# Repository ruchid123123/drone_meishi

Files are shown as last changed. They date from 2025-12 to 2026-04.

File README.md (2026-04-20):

# ESP32 Mini Drone FC

Please see the blog post for full details.
https://fumimaker.net/drone_business_card_rev32

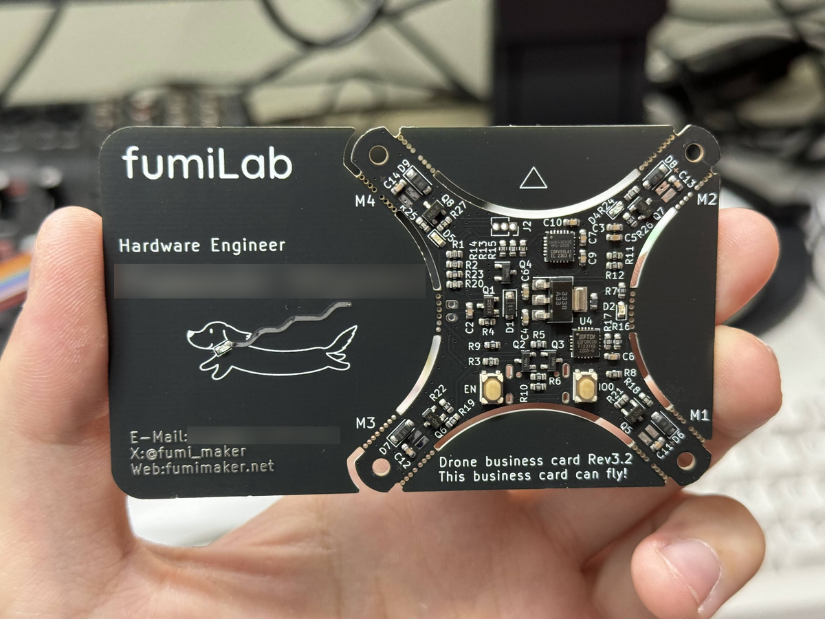
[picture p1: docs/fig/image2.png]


## Overview

Firmware for an ESP32-based micro drone FC with IMU fusion, PID control, and a Web UI controller.

YouTube (https://www.youtube.com/watch?v=yCas-xbfeBE)

---

# ESP32 迷你无人机飞控

详情请参阅博客文章：
https://fumimaker.net/drone_business_card_rev32

## 概述

基于 ESP32 的微型无人机飞控固件，具备 IMU 数据融合、PID 控制和 Web UI 控制器功能。

## 运行时参数

- 控制循环：500 Hz（IMU 读取、姿态估计、PID、电机输出）
- 电机 PWM：20 kHz
- WebSocket 控制输入：50 Hz（Web UI）
- 遥测数据：默认 20 Hz
- Web 服务器/WebSocket：通过 ESPAsyncWebServer + AsyncTCP 事件驱动

## 依赖库

- ESPAsyncWebServer
- AsyncTCP

## 烧录步骤

1. 安装 Arduino IDE + ESP32 核心库
2. 安装上述依赖库
3. 选择 **ESP32 Devkit** 并上传

## 使用方法

1. 上电：ESP32 启动 Wi-Fi 热点
   - SSID: `ESP32-DRONE`
   - 密码: `12345678`
2. 连接后打开 `http://192.168.4.1/`
3. 在 **SETTINGS** 中进行校准：先校准陀螺仪(GYRO)，再校准加速度计(ACC)
4. 如需调整，修改 PID 参数，然后点击 **SAVE** 保存
5. 切换到 **CONTROL** 页面，启用 **ARM**（约 800 秒后解锁），然后飞行
6. **DISARM** 立即停止；倾斜角度 > ~80° 自动解锁

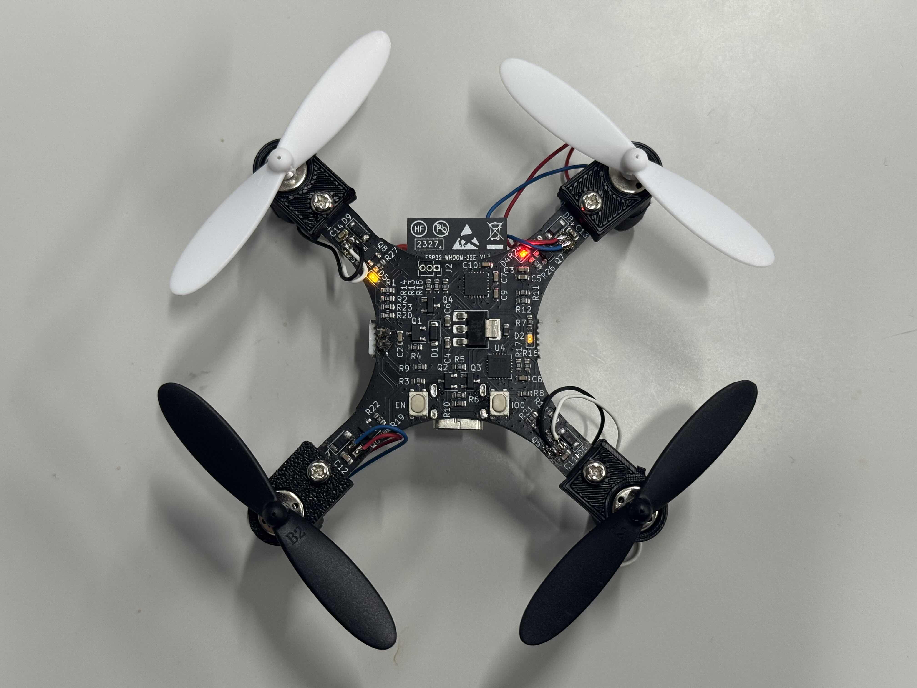
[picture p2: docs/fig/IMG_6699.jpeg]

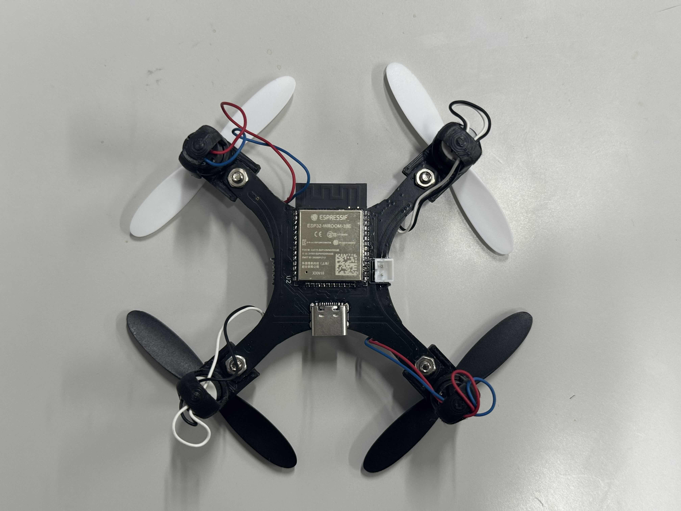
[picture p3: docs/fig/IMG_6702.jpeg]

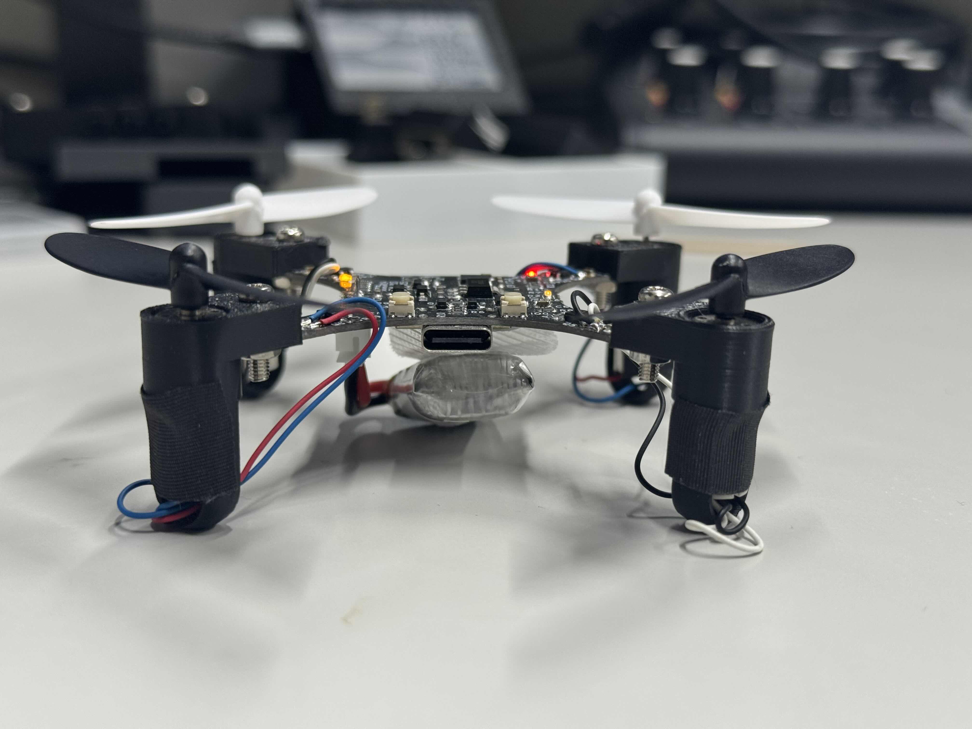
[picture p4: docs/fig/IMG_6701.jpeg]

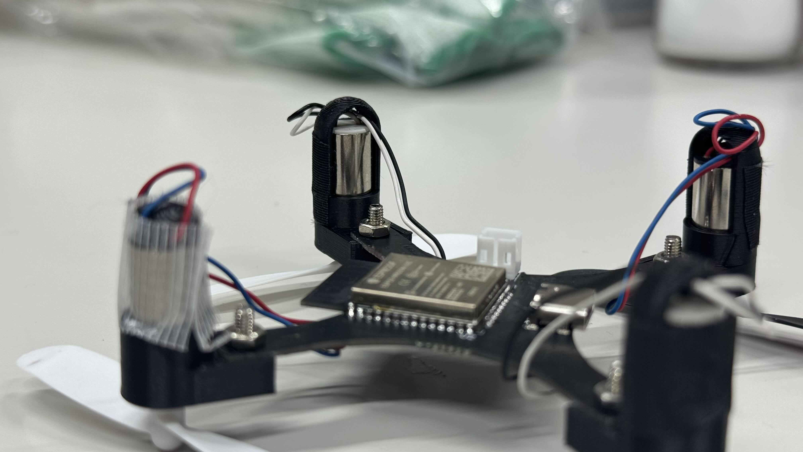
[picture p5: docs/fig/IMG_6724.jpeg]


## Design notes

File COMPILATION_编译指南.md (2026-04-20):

# ESP32 迷你无人机飞控 - 编译指南 (2026年版)

本指南详细说明了如何在受限网络环境下，利用国内加速镜像和 Docker 成功编译本项目。

---

## 1. 快速开始 (推荐方案：Docker 挂载模式)

由于 ESP32 工具链体积庞大（约 300MB+），在 Docker 内部直接下载极易失败。推荐在宿主机下载环境后，通过 Docker 挂载运行。

### 准备环境 (宿主机)
1. **安装工具**：确保 `arduino-cli` 已安装（本项目路径为 `/home/j/bin/arduino-cli`）。
2. **配置国内加速镜像** (乐鑫官方极狐镜像)：
   ```bash
   arduino-cli config init --overwrite
   arduino-cli config add board_manager.additional_urls https://jihulab.com/esp-mirror/espressif/arduino-esp32/-/raw/gh-pages/package_esp32_index_cn.json
   arduino-cli core update-index
   ```
3. **安装核心库** (必须带 `-cn` 后缀以触发国内加速)：
   ```bash
   arduino-cli core install esp32:esp32@3.0.7-cn
   ```
4. **安装依赖库**：
   ```bash
   arduino-cli lib install "ESPAsyncWebServer" "AsyncTCP"
   ```

### 使用 Docker 编译
运行项目根目录下的脚本：
```bash
chmod +x docker_compile.sh
./docker_compile.sh
```
该脚本会将宿主机的 `~/.arduino15`（环境）和 `~/Arduino/libraries`（库）挂载到容器中，实现环境隔离与高速编译的平衡。

---

## 2. 关键补丁与修复 (已在本项目中应用)

在编译过程中，我们解决了以下两个核心冲突，后续开发请务必注意：

### 2.1 修复代码重定义错误
在 `drone_meishi.ino` 中，`kEnableSerialAttDebug` 曾被定义了两次，导致编译失败。已删除冗余定义。

### 2.2 修复 ESPAsyncWebServer 兼容性
由于 ESP32 Arduino Core 3.0.x 升级了 `mbedtls` 库，旧版 `ESPAsyncWebServer` 中的加密函数后缀不匹配。需对库文件进行如下替换：
- `mbedtls_md5_starts_ret` -> `mbedtls_md5_starts`
- `mbedtls_md5_update_ret` -> `mbedtls_md5_update`
- `mbedtls_md5_finish_ret` -> `mbedtls_md5_finish`
*注：本项目宿主机环境已完成此修复。*

---

## 3. 故障排除

### 网络超时
- **Docker 拉取镜像慢**：已配置 `/etc/docker/daemon.json` 使用国内镜像（如 `docker.xuanyuan.me`）。
- **Arduino 核心库下载失败**：请检查是否使用了 `package_esp32_index_cn.json` 并选择了 `-cn` 版本。

### 编译命令参考
- **完整编译指令**：
  ```bash
  arduino-cli compile --fqbn esp32:esp32:esp32 drone_meishi/drone_meishi.ino
  ```

---

## 4. 文件说明
- `Dockerfile.build`：用于构建基础编译镜像。
- `docker_compile.sh`：一键调用 Docker 进行编译的入口。
- `arduino-cli-bin`：为 Docker 构建准备的本地工具二进制文件。

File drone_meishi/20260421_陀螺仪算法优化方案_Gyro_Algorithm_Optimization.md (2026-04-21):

# 陀螺仪算法优化方案 (2026-04-21)

针对本项目（Drone Meishi）使用的 MPU6050 硬件及 Mahony/Madgwick 融合算法，提出以下优化路径，旨在提升飞行稳定性、减少姿态漂移并增强抗震动能力。

## 1. 硬件层优化 (MPU6050 配置)
*   **启用内置数字低通滤波器 (DLPF)**：目前驱动层可以增加对 `CONFIG (0x1A)` 寄存器的配置。建议将 DLPF 设置为 42Hz 或 20Hz，以在源头上滤除电机高频机械振动。
*   **采样率同步**：确保 MPU6050 的内部采样率（Sample Rate）与飞控主循环（500Hz）保持倍数同步，减少混叠噪声。

## 2. 核心算法改进 (Mahony/Madgwick)
*   **动态增益控制 (Adaptive Gains)**：
    *   **运动感知**：在检测到剧烈加速或旋转时，动态降低加速度计的反馈权重（Kp/Beta），防止非重力加速度干扰姿态。
    *   **静止校准**：在检测到长期静止时，提高权重以快速修正陀螺仪的累积漂移。
*   **加速度计阈值剔除 (G-vector Clipping)**：在 Mahony 算法中加入逻辑：当 `|Acc_total - 1G| > Threshold` 时，暂时停止加速度计的反馈修正。

## 3. 信号处理优化
*   **软件陷波滤波器 (Notch Filter)**：针对电机转速产生的特定频率干扰（通常在 150Hz-300Hz 之间），在 IMU 原始数据进入算法前增加陷波滤波，这比通用的低通滤波更精准且延迟更低。
*   **零偏动态温度补偿**：利用 MPU6050 内置温度计，建立简单的线性模型 `Bias = k * Temp + b`，解决无人机工作一段时间发热后产生的侧偏现象。

## 4. 系统执行优化 (ESP32 特性)
*   **多核并行处理**：将 `IMU Read + AHRS Update` 任务锁定在 ESP32 的 Core 0 运行，而将 `Web UI + WiFi` 锁定在 Core 1。避免网络协议栈阻塞导致的姿态计算抖动。
*   **使用硬件浮点优化**：确保算法实现中大量使用 `float` 而非 `double`，并调用 ESP32 的 `rsqrtf` 等 FPU 优化函数进行四元数归一化。

## 5. 预期效果
*   **抗干扰性**：在电机高速转动下，姿态抖动幅度预计降低 30% 以上。
*   **响应速度**：通过减少软件滤波延迟，提升飞控对外部扰动的纠正速度。
*   **长时稳定性**：航向漂移和水平漂移在 5 分钟飞行任务中将更加线性可控。

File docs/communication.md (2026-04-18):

# Communication Architecture

---

## 1. システム全体図

操縦者(スマホ) ↔ ドローン本体(ESP32) ↔ センサ/アクチュエータ、およびオプションのPC接続を含む全体像。

```mermaid
flowchart LR
    subgraph Operator["操縦側"]
        Phone["スマホ / PCブラウザ<br/>Web UI"]
        ProcPC["PC<br/>Processing Viewer<br/>(姿勢可視化)"]
    end

    subgraph Drone["ドローン本体"]
        ESP["ESP32 DevKit<br/>Flight Controller"]
        IMU["MPU6050<br/>6軸IMU"]
        ESC["4× Motor / ESC<br/>(M0–M3)"]
        NVS[("NVS Flash<br/>PID/Cal保存")]
    end

    Phone <-->|"Wi-Fi 2.4GHz<br/>SoftAP: ESP32-DRONE<br/>HTTP/WebSocket :80"| ESP
    ESP <-->|"I2C 400kHz<br/>SDA=21 / SCL=22<br/>addr 0x68"| IMU
    ESP -->|"PWM 20kHz / 11bit<br/>GPIO 15,13,12,14"| ESC
    ESP <-->|"内蔵SPI Flash"| NVS
    ESP -.->|"USB UART 115200bps<br/>(オプション)"| ProcPC
```

---

## 2. 機体プロペラ配置（Xクアッド）

WebSocket経由の `roll/pitch/yaw/throttle` をモータミキシングで4基に配分。

```mermaid
flowchart TB
    subgraph Frame[" "]
        direction TB
        FRONT(("▲ Front"))
        M0["M0 (FL)<br/>GPIO15<br/>CCW"]
        M1["M1 (FR)<br/>GPIO13<br/>CW"]
        M3["M3 (RL)<br/>GPIO14<br/>CW"]
        M2["M2 (RR)<br/>GPIO12<br/>CCW"]
        FRONT -.- M0
        FRONT -.- M1
    end

    Mix["Motor Mix (X)<br/>M0 = T + R + P − Y<br/>M1 = T − R + P + Y<br/>M2 = T − R − P − Y<br/>M3 = T + R − P + Y"]
    Mix --> M0
    Mix --> M1
    Mix --> M2
    Mix --> M3
```

---

## 3. 制御ループ（500 Hz）

メインループの内部データフロー。IMU読み出しからモータ出力までを2ms周期で回す。

```mermaid
flowchart LR
    A["① IMU読み出し<br/>I2C 14byte"] --> B["② AHRS推定<br/>Mahony / Madgwick / Comp"]
    B --> C["③ 角度PID<br/>(roll/pitch/yaw)"]
    C --> D["④ レートPID"]
    D --> E["⑤ モータミキシング<br/>X-quad"]
    E --> F["⑥ PWM出力<br/>LEDC 20kHz/11bit"]

    G["WebSocket入力<br/>throttle/roll/pitch/yaw"] --> C
    H["フェイルセーフ判定<br/>WS切断/タイムアウト/傾き>80°"] -.-> E
```

---

## 4. WebSocket メッセージ仕様

ブラウザ ↔ ESP32 (`ws://192.168.4.1/ws`) はテキストCSV/JSON。

### Client → Drone

| Type | Format | 用途 | レート |
|---|---|---|---|
| `C` | `C,throttle,roll,pitch,yaw,arm` | 操縦入力 | 50 Hz |
| `PID` | `PID,ANGLE\|RATE\|YAW,kp,ki,kd` | PIDゲイン更新 | 任意 |
| `CFG` | `CFG,KEY,VALUE` | 設定変更 | 任意 |
| `CAL` | `CAL,LEVEL\|GYRO` | キャリブレーション要求 | 任意 |
| `MTEST` | `MTEST,idx,thr,dur_ms` / `MTEST,STOP` | モータテスト | 任意 |
| `GET` | `GET` | 設定同期要求 | 接続時 |
| `SAVE` | `SAVE` | NVSへ保存 | 任意 |
| `K` | `K` | 強制Disarm | 任意 |

### Drone → Client (JSON)

| Type | 主なフィールド | 用途 | レート |
|---|---|---|---|
| `tel` | `t, armed, roll, pitch, yaw, m0..m3, vbatt, loop_hz, fs, cmd_age` | テレメトリ | 20 Hz |
| `cfg` | PID/制限/オフセット一式 | 接続時の設定通知 | 接続時 |
| `ack` | `op, tag, ok, msg` | コマンド応答 | 都度 |

### 操縦シーケンス例

```mermaid
sequenceDiagram
    participant B as 📱 Browser
    participant E as ESP32 (FC)
    participant I as MPU6050
    participant M as Motors

    B->>E: HTTP GET /  (UI HTML)
    B->>E: WS connect /ws
    E-->>B: cfg (現在のPID/設定)
    loop 50Hz
        B->>E: C,throttle,roll,pitch,yaw,arm
    end
    loop 500Hz (内部)
        E->>I: I2C read 14B
        I-->>E: ax,ay,az,gx,gy,gz
        E->>M: PWM (M0..M3)
    end
    loop 20Hz
        E-->>B: tel JSON
    end
    Note over B,E: WS切断 → 即Disarm<br/>cmd_age > 300ms → Disarm
```

---

## 5. ピン/ポート割当

| 機能 | 信号 | GPIO / ポート | 備考 |
|---|---|---|---|
| I2C IMU | SDA | GPIO 21 | 400 kHz |
| I2C IMU | SCL | GPIO 22 | addr 0x68 |
| Motor M0 (FL) | PWM | GPIO 15 | LEDC ch0 |
| Motor M1 (FR) | PWM | GPIO 13 | LEDC ch1 |
| Motor M2 (RR) | PWM | GPIO 12 | LEDC ch2 |
| Motor M3 (RL) | PWM | GPIO 14 | LEDC ch3 |
| Web Server | TCP | :80 (HTTP / WS) | ESPAsyncWebServer |
| Wi-Fi | SoftAP | 2.4GHz | SSID `ESP32-DRONE` / IP `192.168.4.1` |
| Debug | UART0 | USB | 115200 bps |

---

## 6. フェイルセーフ

| トリガ | 動作 | 備考 |
|---|---|---|
| WebSocket切断 | 即Disarm | `FS_WS_DISCONNECT` |
| 操縦コマンド未受信 > 300ms | Disarm | `cmd_to` で変更可 |
| 機体傾き > 80° | Auto Disarm | `tilt_dis` で変更可 |
| IMU異常 | Disarm | 姿勢推定値が不正な場合 |
| Armラッチ後の再Arm抑止 | キル状態保持 | 明示的にDisarm要求が必要 |

---

## 7. 通信
操縦は **Wi-Fi WebSocket**
ライブラリ依存は `ESPAsyncWebServer` / `AsyncTCP`

以下は使用していません．
- SBUS（プロポ受信機）
- ESP-NOW
- Bluetooth
- MAVLink / CRSF / S.Port 等のテレメトリ規格

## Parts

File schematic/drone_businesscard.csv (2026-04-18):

Reference | Qty | Value | DNP | Exclude from BOM | Exclude from Board | Footprint | Datasheet
C1 | 1 | DNP |  |  |  | Capacitor_SMD:C_0603_1608Metric | ~
C2,C5,C7,C8,C9,C10,C11,C12,C13,C14 | 10 | 0.1u |  |  |  | Capacitor_SMD:C_0603_1608Metric | ~
C3,C4,C6 | 3 | 10u |  |  |  | Capacitor_SMD:C_0603_1608Metric | ~
D1 | 1 | MBR0520 |  |  |  | Diode_SMD:D_SOD-123 | http://www.mccsemi.com/up_pdf/MBR0520~MBR0580(SOD123).pdf
D2 | 1 | blue |  |  |  | LED_SMD:LED_0603_1608Metric | ~
D3,D4 | 2 | red |  |  |  | LED_SMD:LED_0603_1608Metric | ~
D5 | 1 | green |  |  |  | LED_SMD:LED_0603_1608Metric | ~
D6,D7,D8,D9 | 4 | 1N4148W |  |  |  | Diode_SMD:D_SOD-123 | https://www.vishay.com/docs/85748/1n4148w.pdf
FB1 | 1 | FerriteBead |  |  |  | Inductor_SMD:L_0603_1608Metric | ~
J1 | 1 | LIPO |  |  |  | Connector_JST:JST_PH_B2B-PH-K_1x02_P2.00mm_Vertical | ~
J2 | 1 | Conn_01x03_Pin |  |  |  | Connector_PinSocket_1.27mm:PinSocket_1x03_P1.27mm_Vertical | ~
J3 | 1 | M1 |  |  |  | Akizuki:1x02_smd_pad | ~
J4 | 1 | M3 |  |  |  | Akizuki:1x02_smd_pad | ~
J5 | 1 | M2 |  |  |  | Akizuki:1x02_smd_pad | ~
J6 | 1 | M4 |  |  |  | Akizuki:1x02_smd_pad | ~
P1 | 1 | USB_C_Plug_USB2.0 |  |  |  | Connector_USB:USB_C_Receptacle_HCTL_HC-TYPE-C-16P-01A | https://www.usb.org/sites/default/files/documents/usb_type-c.zip
Q1 | 1 | AO3401A |  |  |  | Package_TO_SOT_SMD:SOT-23 | http://www.aosmd.com/pdfs/datasheet/AO3401A.pdf
Q2,Q3,Q4 | 3 | MMBT3904 |  |  |  | Package_TO_SOT_SMD:SOT-23 | https://www.onsemi.com/pdf/datasheet/pzt3904-d.pdf
Q5,Q6,Q7,Q8 | 4 | AO3400A |  |  |  | Package_TO_SOT_SMD:SOT-23 | http://www.aosmd.com/pdfs/datasheet/AO3400A.pdf
R1,R2 | 2 | 2.2k |  |  |  | Resistor_SMD:R_0603_1608Metric | ~
R3,R4,R5,R6,R7,R8,R9,R11,R12,R14,R15,R21,R22,R26,R27 | 15 | 10k |  |  |  | Resistor_SMD:R_0603_1608Metric | ~
R10 | 1 | 5.1k |  |  |  | Resistor_SMD:R_0603_1608Metric | ~
R13,R16,R17,R18,R19,R20,R23,R24,R25 | 9 | 1k |  |  |  | Resistor_SMD:R_0603_1608Metric | ~
SW1,SW2 | 2 | SW_MEC_5E |  |  |  | module:SKRPACE010 | http://www.apem.com/int/index.php?controller=attachment&id_attachment=1371
U1 | 1 | LT1117-3.3 |  |  |  | Package_TO_SOT_SMD:SOT-223-3_TabPin2 | https://www.analog.com/media/en/technical-documentation/data-sheets/1117fd.pdf
U2 | 1 | ESP32-WROOM-32D |  |  |  | RF_Module:ESP32-WROOM-32D | https://www.espressif.com/sites/default/files/documentation/esp32-wroom-32d_esp32-wroom-32u_datasheet_en.pdf
U3 | 1 | MPU-6050 |  |  |  | Sensor_Motion:InvenSense_QFN-24_4x4mm_P0.5mm | https://invensense.tdk.com/wp-content/uploads/2015/02/MPU-6000-Datasheet1.pdf
U4 | 1 | FT231XQ |  |  |  | Package_DFN_QFN:QFN-20-1EP_4x4mm_P0.5mm_EP2.5x2.5mm | https://www.ftdichip.com/Support/Documents/DataSheets/ICs/DS_FT231X.pdf

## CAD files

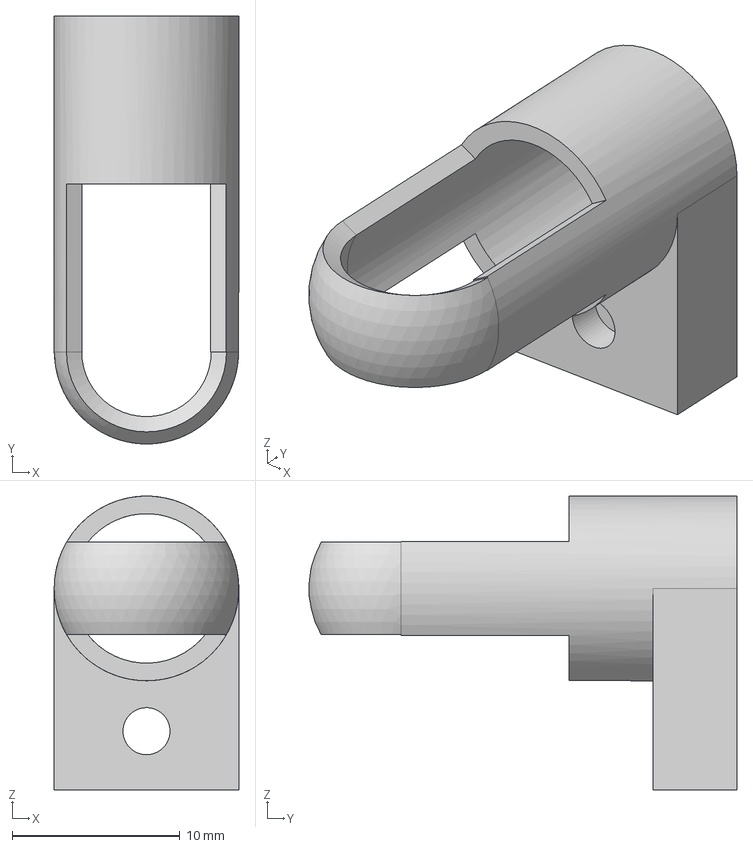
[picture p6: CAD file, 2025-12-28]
3dmodel/drone_meishi3.step
11.0 x 25.5 x 17.5 mm

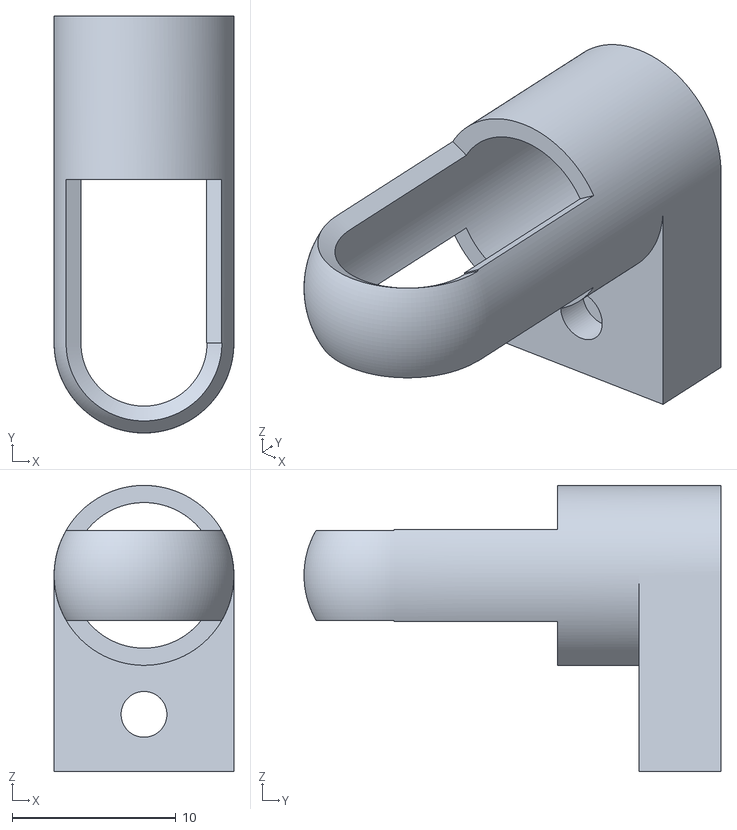
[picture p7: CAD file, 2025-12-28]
3dmodel/drone_meishi.stl
11.0 x 25.5 x 17.5

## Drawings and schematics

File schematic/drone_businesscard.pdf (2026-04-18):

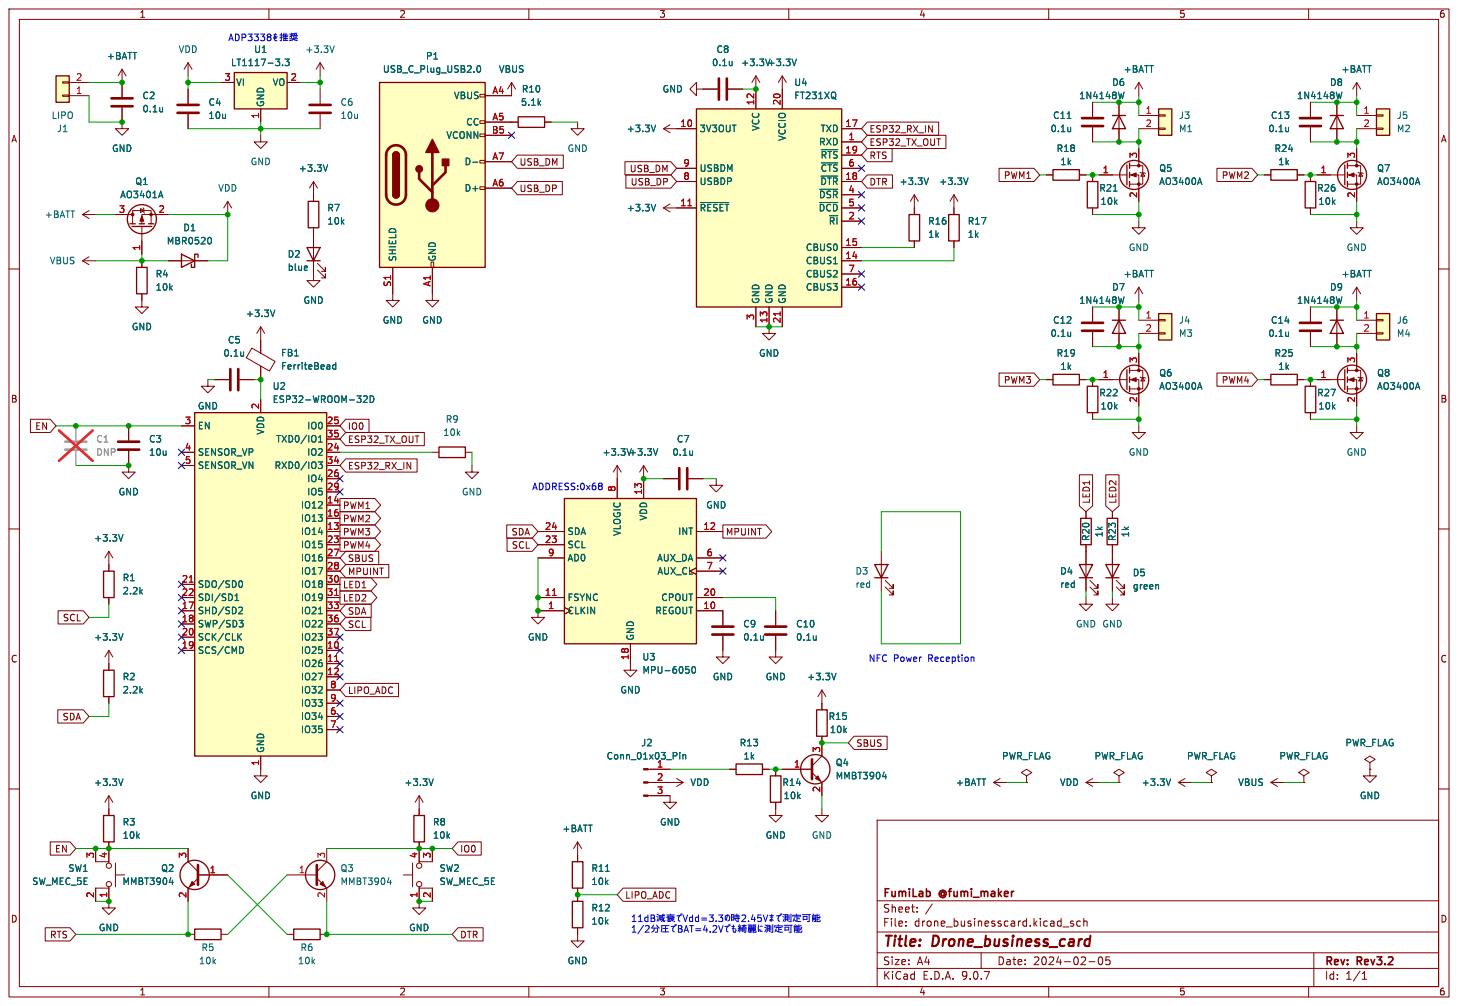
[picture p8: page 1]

3 2 Q5 AO3400A SHIELD S1 GND A1 VBUS A4 CC A5 VCONN B5 D- A7 D+ A6 P1 USB_C_Plug_USB2.0 +3.3V C6

3 GND 13 VCCIO 20 GND 21 TXD 17 RXD 1 ~{RTS}19 ~{CTS}6 ~{DTR}18 ~{DSR}4 ~{DCD}5 ~{RI}2 CBUS0 15 CBUS1 14 CBUS2 7 CBUS3 16 +3.3V +3.3V GND

3 GND 13 VCCIO 20 GND 21 TXD 17 RXD 1 ~{RTS}19 ~{CTS}6 ~{DTR}18 ~{DSR}4 ~{DCD}5 ~{RI}2 CBUS0 15 CBUS1 14 CBUS2 7 CBUS3 16 U4 FT231XQ

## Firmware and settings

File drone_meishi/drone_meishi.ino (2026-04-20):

#include <Arduino.h>
#include <AsyncTCP.h>
#include <ESPAsyncWebServer.h>
#include <Preferences.h>
#include <WiFi.h>
#include <Wire.h>
#include <math.h>
#include <string.h>
#include <esp32-hal-ledc.h>
#include "drone_types.h"

// ============================================================
// Pin Configuration / 引脚配置
// ============================================================

// WiFi AP settings / WiFi 热点设置
static const char *kApSsid = "ESP32-DRONE";
static const char *kApPass = "12345678";

// I2C pins / I2C 引脚
static const int kI2cSda = 21;
static const int kI2cScl = 22;
static const uint8_t kMpuAddr = 0x68;

// IMU axis mapping (sensor -> body frame)
// Configure these to match your board orientation.
// IMU 轴向映射（传感器 -> 机体坐标系），根据板子方向配置。
static const bool kImuSwapXY = true;
static const bool kImuFlipX = true;   // Right roll -> positive
static const bool kImuFlipY = true;   // Pitch up -> positive
static const bool kImuFlipZ = false;

// Motors (X configuration) / 电机（X 型布局）
// Front is between M0/M1. Order: FL, FR, RR, RL
// 前方在 M0/M1 之间。顺序：前左、前右、后右、后左
static const int kMotor0Pin = 15;  // Front Left
static const int kMotor1Pin = 13;  // Front Right
static const int kMotor2Pin = 12;  // Rear Right
static const int kMotor3Pin = 14;  // Rear Left

static const float kMotorTestMaxThrottle = 0.20f;
static const uint32_t kMotorTestMinMs = 100;
static const uint32_t kMotorTestMaxMs = 2000;

// LEDs (LED1: right, LED2: left) / LED（LED1：右，LED2：左）
static const int led1 = 18;
static const int led2 = 19;

// PWM settings / PWM 设置
static const uint32_t kPwmFreqHz = 20000;
static const uint8_t kPwmResolutionBits = 11;
static const uint32_t kPwmMaxDuty = (1U << kPwmResolutionBits) - 1U;

static const uint32_t kLedPwmFreqHz = 1000;
static const uint8_t kLedPwmResolutionBits = 8;
static const uint32_t kLedPwmMaxDuty = (1U << kLedPwmResolutionBits) - 1U;


// Control loop timing / 控制循环时序
static const uint32_t kLoopPeriodUs = 2000;  // 500Hz
static const float kDtMaxSec = 0.02f;

// RC and arming parameters / 遥控和解锁参数
static const uint32_t kDefaultCmdTimeoutMs = 300;
static const uint32_t kMinCmdTimeoutMs = 100;
static const uint32_t kMaxCmdTimeoutMs = 2000;
static const float kArmThrottleMax = 0.05f;
static const float kStickCenterMax = 0.15f;
static const uint32_t kArmHoldMs = 800;

// Torque scaling / 扭矩缩放
// Helps avoid lift at very low throttle.
// 防止在低油门时产生升力。
static const float kDefaultTorqueScaleSlope = 2.0f;  // throttle * slope -> torque scale (0..1)
static const float kDefaultTorqueScaleMin = 0.20f;   // floor to keep some authority at 0 throttle
static const float kMinTorqueScaleSlope = 0.0f;
static const float kMaxTorqueScaleSlope = 4.0f;
static const float kMinTorqueScaleMin = 0.0f;
static const float kMaxTorqueScaleMin = 1.0f;

// Flight limits / 飞行限制
static const float kDefaultMaxAngleDeg = 30.0f;
static const float kMinMaxAngleDeg = 5.0f;
static const float kMaxMaxAngleDeg = 80.0f;
static const float kDefaultMaxYawRateDps = 180.0f;
static const float kMinMaxYawRateDps = 30.0f;
static const float kMaxMaxYawRateDps = 360.0f;
static const float kDefaultTiltDisarmDeg = 80.0f;
static const float kMinTiltDisarmDeg = 20.0f;
static const float kMaxTiltDisarmDeg = 85.0f;

// Telemetry / 遥测
static const uint32_t kDefaultTelemPeriodMs = 50;  // 20Hz
static const uint32_t kMinTelemPeriodMs = 20;
static const uint32_t kMaxTelemPeriodMs = 500;

// IMU filter settings / IMU 滤波器设置
static const float kMadgwickBeta = 0.08f;
static const float kMadgwickBetaMin = 0.02f;
static const float kMadgwickBetaMax = 0.14f;

// Betaflight-style Mahony (DCM) gains / Betaflight 风格 Mahony 增益
// - Kp: proportional correction strength / 比例校正强度
// - Ki: integral correction strength / 积分校正强度
static const float kMahonyKp = 2.2f;
static const float kMahonyKi = 0.0f;
static const float kMahonyIntegralLimitRads = 0.35f;  // clamp for bias estimate (rad/s)
static const float kMahonySpinLimitDps = 180.0f;      // disable integral update above this rate

static const float kAccTrustHi = 0.08f;  // |norm-1| <= this -> full trust
static const float kAccTrustLo = 0.35f;  // |norm-1| >= this -> no trust

enum FilterMode : uint8_t {
  FILTER_MADGWICK = 0,
  FILTER_MAHONY = 1,
  FILTER_COMP = 2,
};

// Default AHRS mode. For Angle flight, Mahony is usually a good starting point.
static const FilterMode kFilterMode = FILTER_MAHONY;

static const float kCompAlpha = 0.98f;  // complementary blend (gyro vs acc)

static const float kRelevelAccTolG = 0.10f;
static const float kRelevelGyroDps = 1.5f;
static const uint32_t kRelevelHoldMs = 400;

// Battery telemetry / 电池遥测

static const int kVbattAdcPin = -1;         // e.g. 34
static const float kVbattDividerRatio = 2.0f;  // voltage divider ratio (VBAT = Vadc * ratio)

// Debug output / 调试输出
static const bool kEnableSerialAttDebug = false;  // High-rate attitude output / 高速姿态输出

// ============================================================
// Utilities
// ============================================================

static inline float clampf(float v, float vmin, float vmax) {
  if (v < vmin) {
    return vmin;
  }
  if (v > vmax) {
    return vmax;
  }
  return v;
}

static inline uint32_t clampu32(uint32_t v, uint32_t vmin, uint32_t vmax) {
  if (v < vmin) {
    return vmin;
  }
  if (v > vmax) {
    return vmax;
  }
  return v;
}

static inline bool isFinitef(float v) {
  return isfinite(v) != 0;
}

// ============================================================
// LED status
// ============================================================
#include "drone_led.h"

// ============================================================
// Web UI
// ============================================================
#include "drone_web_ui.h"

// ============================================================
// RC command
// ============================================================

static RcCommand g_rc = {0.0f, 0.0f, 0.0f, 0.0f, false, 0};
static portMUX_TYPE g_rcMux = portMUX_INITIALIZER_UNLOCKED;

static RcCommand getRcCommand() {
  RcCommand out;
  portENTER_CRITICAL(&g_rcMux);
  out = g_rc;
  portEXIT_CRITICAL(&g_rcMux);
  return out;
}

static void setRcCommand(float throttle, float roll, float pitch, float yaw, bool arm_request) {
  portENTER_CRITICAL(&g_rcMux);
  g_rc.throttle = clampf(throttle, 0.0f, 1.0f);
  g_rc.roll = clampf(roll, -1.0f, 1.0f);
  g_rc.pitch = clampf(pitch, -1.0f, 1.0f);
  g_rc.yaw = clampf(yaw, -1.0f, 1.0f);
  g_rc.arm_request = arm_request;
  g_rc.last_ms = millis();
  portEXIT_CRITICAL(&g_rcMux);
}

// ============================================================
// PID
// ============================================================
#include "drone_pid.h"

// ============================================================
// Madgwick IMU-only
// ============================================================
#include "drone_imu.h"

// ============================================================
// PID tunings + NVS
// ============================================================

static RuntimeConfig g_config = {
  kDefaultMaxAngleDeg,
  kDefaultMaxYawRateDps,
  kDefaultTiltDisarmDeg,
  kDefaultCmdTimeoutMs,
  kDefaultTelemPeriodMs,
  kDefaultTorqueScaleMin,
  kDefaultTorqueScaleSlope,
};

static Tunings g_tunings = {
  {2.0f, 0.001f, 0.0f},     // angle
  {0.025f, 0.0f, 0.0002f},  // rate
  {0.030f, 0.0f, 0.0f},     // yaw
};

static float g_level_roll_offset_deg = 0.0f;
static float g_level_pitch_offset_deg = 0.0f;
static float g_level_yaw_offset_deg = 0.0f;

static volatile bool g_tunings_dirty = false;
static portMUX_TYPE g_cfgMux = portMUX_INITIALIZER_UNLOCKED;

// Active AHRS mode (switchable). Protected by g_cfgMux.
static FilterMode g_filter_mode = kFilterMode;

static Preferences g_prefs;

static void clampConfig(RuntimeConfig *cfg) {
  cfg->max_angle_deg = clampf(cfg->max_angle_deg, kMinMaxAngleDeg, kMaxMaxAngleDeg);
  cfg->max_yaw_rate_dps = clampf(cfg->max_yaw_rate_dps, kMinMaxYawRateDps, kMaxMaxYawRateDps);
  cfg->tilt_disarm_deg = clampf(cfg->tilt_disarm_deg, kMinTiltDisarmDeg, kMaxTiltDisarmDeg);
  cfg->cmd_timeout_ms = clampu32(cfg->cmd_timeout_ms, kMinCmdTimeoutMs, kMaxCmdTimeoutMs);
  cfg->telem_period_ms = clampu32(cfg->telem_period_ms, kMinTelemPeriodMs, kMaxTelemPeriodMs);
  cfg->torque_scale_min = clampf(cfg->torque_scale_min, kMinTorqueScaleMin, kMaxTorqueScaleMin);
  cfg->torque_scale_slope = clampf(cfg->torque_scale_slope, kMinTorqueScaleSlope, kMaxTorqueScaleSlope);
}

static void loadTunings() {
  g_prefs.begin("drone", true);

  g_tunings.angle.kp = g_prefs.getFloat("a_kp", g_tunings.angle.kp);
  g_tunings.angle.ki = g_prefs.getFloat("a_ki", g_tunings.angle.ki);
  g_tunings.angle.kd = g_prefs.getFloat("a_kd", g_tunings.angle.kd);

  g_tunings.rate.kp = g_prefs.getFloat("r_kp", g_tunings.rate.kp);
  g_tunings.rate.ki = g_prefs.getFloat("r_ki", g_tunings.rate.ki);
  g_tunings.rate.kd = g_prefs.getFloat("r_kd", g_tunings.rate.kd);

  g_tunings.yaw.kp = g_prefs.getFloat("y_kp", g_tunings.yaw.kp);
  g_tunings.yaw.ki = g_prefs.getFloat("y_ki", g_tunings.yaw.ki);
  g_tunings.yaw.kd = g_prefs.getFloat("y_kd", g_tunings.yaw.kd);

  g_config.max_angle_deg = g_prefs.getFloat("max_ang", g_config.max_angle_deg);
  g_config.max_yaw_rate_dps = g_prefs.getFloat("max_yaw", g_config.max_yaw_rate_dps);
  g_config.tilt_disarm_deg = g_prefs.getFloat("tilt_dis", g_config.tilt_disarm_deg);
  g_config.cmd_timeout_ms = g_prefs.getUInt("cmd_to", g_config.cmd_timeout_ms);
  g_config.telem_period_ms = g_prefs.getUInt("telem_ms", g_config.telem_period_ms);
  g_config.torque_scale_min = g_prefs.getFloat("tq_min", g_config.torque_scale_min);
  g_config.torque_scale_slope = g_prefs.getFloat("tq_slope", g_config.torque_scale_slope);
  clampConfig(&g_config);

  g_level_roll_offset_deg = g_prefs.getFloat("lvl_roll", g_level_roll_offset_deg);
  g_level_pitch_offset_deg = g_prefs.getFloat("lvl_pitch", g_level_pitch_offset_deg);
  g_level_yaw_offset_deg = g_prefs.getFloat("lvl_yaw", g_level_yaw_offset_deg);

  // IMU/AHRS filter mode (0:Madgwick, 1:Mahony, 2:Complementary)
  const uint32_t imu_filt = g_prefs.getUInt("imu_filt", (uint32_t)g_filter_mode);
  if (imu_filt <= (uint32_t)FILTER_COMP) {
    g_filter_mode = (FilterMode)imu_filt;
  }

  g_prefs.end();
}

static void saveTunings() {
  g_prefs.begin("drone", false);

  g_prefs.putFloat("a_kp", g_tunings.angle.kp);
  g_prefs.putFloat("a_ki", g_tunings.angle.ki);
  g_prefs.putFloat("a_kd", g_tunings.angle.kd);

  g_prefs.putFloat("r_kp", g_tunings.rate.kp);
  g_prefs.putFloat("r_ki", g_tunings.rate.ki);
  g_prefs.putFloat("r_kd", g_tunings.rate.kd);

  g_prefs.putFloat("y_kp", g_tunings.yaw.kp);
  g_prefs.putFloat("y_ki", g_tunings.yaw.ki);
  g_prefs.putFloat("y_kd", g_tunings.yaw.kd);

  g_prefs.putFloat("max_ang", g_config.max_angle_deg);
  g_prefs.putFloat("max_yaw", g_config.max_yaw_rate_dps);
  g_prefs.putFloat("tilt_dis", g_config.tilt_disarm_deg);
  g_prefs.putUInt("cmd_to", g_config.cmd_timeout_ms);
  g_prefs.putUInt("telem_ms", g_config.telem_period_ms);
  g_prefs.putFloat("tq_min", g_config.torque_scale_min);
  g_prefs.putFloat("tq_slope", g_config.torque_scale_slope);

  g_prefs.putFloat("lvl_roll", g_level_roll_offset_deg);
  g_prefs.putFloat("lvl_pitch", g_level_pitch_offset_deg);
  g_prefs.putFloat("lvl_yaw", g_level_yaw_offset_deg);

  g_prefs.putUInt("imu_filt", (uint32_t)g_filter_mode);

  g_prefs.end();
}

// ============================================================
// Globals
// ============================================================

static AsyncWebServer g_server(80);
static AsyncWebSocket g_ws("/ws");

static Mpu6050 g_mpu;
static MadgwickImu g_ahrs_madgwick;
static MahonyImu g_ahrs_mahony;

static uint32_t g_stationary_start_ms = 0;

static Pid g_roll_angle_pid;
static Pid g_pitch_angle_pid;
static Pid g_roll_rate_pid;
static Pid g_pitch_rate_pid;
static Pid g_yaw_rate_pid;

static float g_roll_deg = 0.0f;
static float g_pitch_deg = 0.0f;
static float g_yaw_deg = 0.0f;

static float g_motor_last[4] = {0, 0, 0, 0};

struct MotorTestState {
  bool active;
  uint8_t index;
  float throttle;
  uint32_t until_ms;
};

static MotorTestState g_motor_test = {false, 0, 0.0f, 0};
static portMUX_TYPE g_motorTestMux = portMUX_INITIALIZER_UNLOCKED;

static bool g_armed = false;
static bool g_arm_inhibit = false;
static bool g_motor_fault = false;
static uint32_t g_arm_hold_start_ms = 0;

enum FailSafeReason : uint8_t {
  FS_NONE = 0,
  FS_CMD_TIMEOUT = 1,
  FS_WS_DISCONNECT = 2,
  FS_IMU_FAIL = 3,
  FS_TILT_LIMIT = 4,
  FS_DT_LIMIT = 5,
  FS_KILL = 6,
  FS_MANUAL = 7,
  FS_MOTOR_FAIL = 8,
};

static uint8_t g_last_fs = FS_NONE;

static volatile bool g_kill_pending = false;
static volatile uint8_t g_kill_reason = FS_KILL;
static portMUX_TYPE g_killMux = portMUX_INITIALIZER_UNLOCKED;

static uint32_t g_last_telem_ms = 0;
static bool g_comp_init = false;
static float g_comp_roll_deg = 0.0f;
static float g_comp_pitch_deg = 0.0f;
static float g_comp_yaw_deg = 0.0f;

enum CalRequest : uint8_t {
  CAL_REQ_NONE = 0,   // No calibration / 无校准
  CAL_REQ_LEVEL = 1,  // Level calibration / 水平校准
  CAL_REQ_GYRO = 2,   // Gyro calibration / 陀螺仪校准
  CAL_REQ_ACC = 3,    // Accel calibration / 加速度计校准
};

enum CalState : uint8_t {
  CAL_STATE_IDLE = 0,  // Idle / 空闲
  CAL_STATE_LEVEL = 1, // Leveling / 水平校准中
  CAL_STATE_GYRO = 2,  // Gyro cal / 陀螺仪校准中
  CAL_STATE_ACC = 3,   // Accel cal / 加速度计校准中
  CAL_STATE_FAIL = 4,  // Failed / 失败
};

static volatile uint8_t g_cal_request = CAL_REQ_NONE;
static portMUX_TYPE g_calMux = portMUX_INITIALIZER_UNLOCKED;
static uint8_t g_cal_state = CAL_STATE_IDLE;
static uint32_t g_cal_state_until_ms = 0;

static char g_status_msg[96] = "";
static void setStatusMsg(const char *msg);
static void setStatusMsgFs(uint8_t reason);

// ============================================================
// Motor
// ============================================================

static bool motorInit() {
  const bool ok0 = ledcAttach(kMotor0Pin, kPwmFreqHz, kPwmResolutionBits);
  const bool ok1 = ledcAttach(kMotor1Pin, kPwmFreqHz, kPwmResolutionBits);
  const bool ok2 = ledcAttach(kMotor2Pin, kPwmFreqHz, kPwmResolutionBits);
  const bool ok3 = ledcAttach(kMotor3Pin, kPwmFreqHz, kPwmResolutionBits);

  Serial.printf("LEDC attach: %d %d %d %d\n", ok0, ok1, ok2, ok3);

  ledcWrite(kMotor0Pin, 0);
  ledcWrite(kMotor1Pin, 0);
  ledcWrite(kMotor2Pin, 0);
  ledcWrite(kMotor3Pin, 0);

  return ok0 && ok1 && ok2 && ok3;
}


static void motorWriteNorm(int pin, float u) {
  const float uu = clampf(u, 0.0f, 1.0f);
  const uint32_t duty = (uint32_t)lrintf(uu * (float)kPwmMaxDuty);
  ledcWrite((uint8_t)pin, duty);
}

static void motorsWriteAll(float m0, float m1, float m2, float m3) {
  g_motor_last[0] = m0;
  g_motor_last[1] = m1;
  g_motor_last[2] = m2;
  g_motor_last[3] = m3;
  motorWriteNorm(kMotor0Pin, m0);
  motorWriteNorm(kMotor1Pin, m1);
  motorWriteNorm(kMotor2Pin, m2);
  motorWriteNorm(kMotor3Pin, m3);
}

static void stopMotorTest() {
  portENTER_CRITICAL(&g_motorTestMux);
  g_motor_test.active = false;
  g_motor_test.throttle = 0.0f;
  g_motor_test.until_ms = 0;
  portEXIT_CRITICAL(&g_motorTestMux);
}

static bool startMotorTest(uint8_t index, float throttle, uint32_t duration_ms) {
  if (index > 3) {
    return false;
  }
  const float thr = clampf(throttle, 0.0f, kMotorTestMaxThrottle);
  if (thr <= 0.0f) {
    stopMotorTest();
    return false;
  }
  const uint32_t dur = clampu32(duration_ms, kMotorTestMinMs, kMotorTestMaxMs);
  const uint32_t until_ms = millis() + dur;

  portENTER_CRITICAL(&g_motorTestMux);
  g_motor_test.active = true;
  g_motor_test.index = index;
  g_motor_test.throttle = thr;
  g_motor_test.until_ms = until_ms;
  portEXIT_CRITICAL(&g_motorTestMux);

  return true;
}

static bool getMotorTestState(MotorTestState *out) {
  if (out == nullptr) {
    return false;
  }
  portENTER_CRITICAL(&g_motorTestMux);
  *out = g_motor_test;
  portEXIT_CRITICAL(&g_motorTestMux);
  return out->active;
}

static void resetAllPid() {
  g_roll_angle_pid.reset();
  g_pitch_angle_pid.reset();
  g_roll_rate_pid.reset();
  g_pitch_rate_pid.reset();
  g_yaw_rate_pid.reset();
}

static void requestKill(uint8_t reason) {
  portENTER_CRITICAL(&g_killMux);
  g_kill_pending = true;
  g_kill_reason = reason;
  portEXIT_CRITICAL(&g_killMux);
}

static void disarmNow(uint8_t reason) {
  g_armed = false;
  g_arm_inhibit = true;
  g_arm_hold_start_ms = 0;
  g_last_fs = reason;
  setStatusMsgFs(reason);
  resetAllPid();
  motorsWriteAll(0.0f, 0.0f, 0.0f, 0.0f);
}

static float readVbatt() {
  if (kVbattAdcPin < 0) {
    return NAN;
  }
#if defined(ARDUINO_ARCH_ESP32)
  const uint32_t mv = analogReadMilliVolts(kVbattAdcPin);
  return ((float)mv / 1000.0f) * kVbattDividerRatio;
#else
  return NAN;
#endif
}

static void requestCalibration(uint8_t req) {
  portENTER_CRITICAL(&g_calMux);
  if (g_cal_request == CAL_REQ_NONE) {
    g_cal_request = req;
  }
  portEXIT_CRITICAL(&g_calMux);
}

static uint8_t takeCalibrationRequest() {
  uint8_t req = CAL_REQ_NONE;
  portENTER_CRITICAL(&g_calMux);
  req = g_cal_request;
  g_cal_request = CAL_REQ_NONE;
  portEXIT_CRITICAL(&g_calMux);
  return req;
}

static void setCalState(uint8_t state, uint32_t hold_ms) {
  g_cal_state = state;
  if (hold_ms > 0) {
    g_cal_state_until_ms = millis() + hold_ms;
  } else {
    g_cal_state_until_ms = 0;
  }
}

static void updateCalState(uint32_t now_ms) {
  if (g_cal_state_until_ms == 0) {
    return;
  }
  if ((int32_t)(now_ms - g_cal_state_until_ms) >= 0) {
    g_cal_state = CAL_STATE_IDLE;
    g_cal_state_until_ms = 0;
  }
}

static const char *calStateLabel(uint8_t state) {
  switch (state) {
    case CAL_STATE_LEVEL:
      return "LEVEL";
    case CAL_STATE_GYRO:
      return "GYRO";
    case CAL_STATE_ACC:
      return "ACC";
    case CAL_STATE_FAIL:
      return "FAIL";
    case CAL_STATE_IDLE:
    default:
      return "IDLE";
  }
}

static const char *failSafeLabel(uint8_t reason) {
  switch (reason) {
    case FS_CMD_TIMEOUT:
      return "CMD_TIMEOUT";
    case FS_WS_DISCONNECT:
      return "WS_DISCONNECT";
    case FS_IMU_FAIL:
      return "IMU_FAIL";
    case FS_TILT_LIMIT:
      return "TILT_LIMIT";
    case FS_DT_LIMIT:
      return "DT_LIMIT";
    case FS_KILL:
      return "KILL";
    case FS_MANUAL:
      return "MANUAL";
    case FS_MOTOR_FAIL:
      return "MOTOR_FAIL";
    case FS_NONE:
    default:
      return "NONE";
  }
}

static const char *motorIndexLabel(uint8_t index) {
  switch (index) {
    case 0:
      return "M0 FL";
    case 1:
      return "M1 FR";
    case 2:
      return "M2 RR";
    case 3:
      return "M3 RL";
    default:
      return "M?";
  }
}

static void setStatusMsg(const char *msg) {
  if (msg == nullptr) {
    g_status_msg[0] = '\0';
    return;
  }
  strncpy(g_status_msg, msg, sizeof(g_status_msg) - 1);
  g_status_msg[sizeof(g_status_msg) - 1] = '\0';
}

static void setStatusMsgFs(uint8_t reason) {
  if (reason == FS_NONE) {
    setStatusMsg("DISARMED");
    return;
  }
  char buf[64];
  snprintf(buf, sizeof(buf), "FAILSAFE: %s", failSafeLabel(reason));
  setStatusMsg(buf);
}

// ============================================================
// Apply tunings to PID objects
// ============================================================

static void applyTunings(const Tunings &t) {
  // Angle PIDs: angle error (deg) -> desired rate (dps)
  g_roll_angle_pid.setGains(t.angle.kp, t.angle.ki, t.angle.kd);
  g_pitch_angle_pid.setGains(t.angle.kp, t.angle.ki, t.angle.kd);
  g_roll_angle_pid.setOutputLimits(-250.0f, 250.0f);
  g_pitch_angle_pid.setOutputLimits(-250.0f, 250.0f);

  // Rate PIDs: rate error (dps) -> torque mix (-0.5..0.5)
  g_roll_rate_pid.setGains(t.rate.kp, t.rate.ki, t.rate.kd);
  g_pitch_rate_pid.setGains(t.rate.kp, t.rate.ki, t.rate.kd);
  g_roll_rate_pid.setOutputLimits(-0.5f, 0.5f);
  g_pitch_rate_pid.setOutputLimits(-0.5f, 0.5f);

  // Yaw rate
  g_yaw_rate_pid.setGains(t.yaw.kp, t.yaw.ki, t.yaw.kd);
  g_yaw_rate_pid.setOutputLimits(-0.3f, 0.3f);
}

static void applyTuningsIfDirty() {
  bool dirty = false;
  Tunings t;

  portENTER_CRITICAL(&g_cfgMux);
  if (g_tunings_dirty) {
    t = g_tunings;
    g_tunings_dirty = false;
    dirty = true;
  }
  portEXIT_CRITICAL(&g_cfgMux);

  if (dirty) {
    applyTunings(t);
    resetAllPid();
  }
}

// ============================================================
// WebSocket protocol
// - C,thr,roll,pitch,yaw,armReq
// - PID,ANGLE,kp,ki,kd
// - PID,RATE,kp,ki,kd
// - PID,YAW,kp,ki,kd
// - CFG,KEY,VALUE (MAX_ANGLE, MAX_YAW_RATE, TILT_DISARM, CMD_TIMEOUT, TELEM_MS,
//                  TORQUE_MIN, TORQUE_SLOPE, IMU_FILTER)
// - GET
// - SAVE
// - CAL,LEVEL|GYRO
// - MTEST,idx,thr,ms | MTEST,STOP
// - K   (kill/disarm)
// ============================================================
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
void loop() {
  static uint32_t last_us = 0;
  static uint32_t next_us = 0;

  ledUpdate();

  const uint32_t now_us = micros();
  if (last_us == 0) {
    last_us = now_us;
    next_us = now_us + kLoopPeriodUs;
    return;
  }

  if ((int32_t)(now_us - next_us) >= 0) {
    while ((int32_t)(now_us - next_us) >= 0) {
      next_us += kLoopPeriodUs;
    }

    const float dt = (now_us - last_us) * 1e-6f;
    last_us = now_us;

    controlStep(dt);
  } else {
    delayMicroseconds(50);
  }
}

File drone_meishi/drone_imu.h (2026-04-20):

#pragma once

// ============================================================
// IMU Sensor Fusion / IMU 传感器融合
// Provides Madgwick, Mahony, and Complementary filters for
// attitude estimation using MPU6050 data.
// 提供 Madgwick、Mahony 和互补滤波器，用于基于 MPU6050 数据的姿态估计。
// ============================================================

// ============================================================
// Madgwick IMU Filter / Madgwick IMU 滤波器
// Quaternion-based attitude estimation with accelerometer correction.
// 基于四元数的姿态估计，带加速度计校正。
// ============================================================

class MadgwickImu {
 public:
  // Initialize filter with beta gain / 使用 beta 增益初始化滤波器
  void begin(float beta) {
    beta_ = beta;
    q0_ = 1.0f;
    q1_ = 0.0f;
    q2_ = 0.0f;
    q3_ = 0.0f;
  }

  // Update beta parameter dynamically / 动态更新 beta 参数
  void setBeta(float beta) {
    if (beta > 0.0f) {
      beta_ = beta;
    }
  }

  // Update attitude estimate / 更新姿态估计
  void update(float gx_rads, float gy_rads, float gz_rads,
              float ax, float ay, float az,
              float dt) {
    float q0 = q0_;
    float q1 = q1_;
    float q2 = q2_;
    float q3 = q3_;

    const float norm_a = sqrtf(ax * ax + ay * ay + az * az);
    if (norm_a < 1e-6f) {
      integrateGyroOnly(gx_rads, gy_rads, gz_rads, dt);
      return;
    }
    ax /= norm_a;
    ay /= norm_a;
    az /= norm_a;

    const float f1 = 2.0f * (q1 * q3 - q0 * q2) - ax;
    const float f2 = 2.0f * (q0 * q1 + q2 * q3) - ay;
    const float f3 = 2.0f * (0.5f - q1 * q1 - q2 * q2) - az;

    const float j_11or24 = -2.0f * q2;
    const float j_12or23 = 2.0f * q3;
    const float j_13or22 = -2.0f * q0;
    const float j_14or21 = 2.0f * q1;
    const float j_32 = 2.0f * j_14or21;
    const float j_33 = 2.0f * j_11or24;

    // NOTE: s = J^T * f (Madgwick original). Sign errors here will cause divergence.
    // 注意：s = J^T * f（Madgwick 原始公式）。符号错误会导致发散。
    float s0 = j_11or24 * f1 + j_14or21 * f2;
    float s1 = j_12or23 * f1 - j_13or22 * f2 - j_32 * f3;
    float s2 = j_13or22 * f1 + j_12or23 * f2 + j_33 * f3;
    float s3 = j_14or21 * f1 - j_11or24 * f2;

    const float norm_s = sqrtf(s0 * s0 + s1 * s1 + s2 * s2 + s3 * s3);
    if (norm_s > 1e-6f) {
      s0 /= norm_s;
      s1 /= norm_s;
      s2 /= norm_s;
      s3 /= norm_s;
    }

    const float qDot0 = 0.5f * (-q1 * gx_rads - q2 * gy_rads - q3 * gz_rads) - beta_ * s0;
    const float qDot1 = 0.5f * ( q0 * gx_rads + q2 * gz_rads - q3 * gy_rads) - beta_ * s1;
    const float qDot2 = 0.5f * ( q0 * gy_rads - q1 * gz_rads + q3 * gx_rads) - beta_ * s2;
    const float qDot3 = 0.5f * ( q0 * gz_rads + q1 * gy_rads - q2 * gx_rads) - beta_ * s3;

    q0 += qDot0 * dt;
    q1 += qDot1 * dt;
    q2 += qDot2 * dt;
    q3 += qDot3 * dt;

    const float norm_q = sqrtf(q0 * q0 + q1 * q1 + q2 * q2 + q3 * q3);
    if (norm_q > 1e-6f) {
      q0 /= norm_q;
      q1 /= norm_q;
      q2 /= norm_q;
      q3 /= norm_q;
    }

    q0_ = q0;
    q1_ = q1;
    q2_ = q2;
    q3_ = q3;
  }

  // Get Euler angles in degrees / 获取欧拉角（度）
  void getEulerDeg(float *roll_deg, float *pitch_deg, float *yaw_deg) const {
    const float q0 = q0_;
    const float q1 = q1_;
    const float q2 = q2_;
    const float q3 = q3_;

    const float roll = atan2f(2.0f * (q0 * q1 + q2 * q3),
                              1.0f - 2.0f * (q1 * q1 + q2 * q2));
    const float sinp = 2.0f * (q0 * q2 - q3 * q1);
    float pitch = 0.0f;
    if (fabsf(sinp) >= 1.0f) {
      pitch = copysignf((float)M_PI / 2.0f, sinp);
    } else {
      pitch = asinf(sinp);
    }
    const float yaw = atan2f(2.0f * (q0 * q3 + q1 * q2),
                             1.0f - 2.0f * (q2 * q2 + q3 * q3));

    *roll_deg = roll * 180.0f / (float)M_PI;
    *pitch_deg = pitch * 180.0f / (float)M_PI;
    *yaw_deg = yaw * 180.0f / (float)M_PI;
  }

  // Set attitude from Euler angles / 从欧拉角设置姿态
  void setEulerDeg(float roll_deg, float pitch_deg, float yaw_deg) {
    const float roll = roll_deg * (float)M_PI / 180.0f;
    const float pitch = pitch_deg * (float)M_PI / 180.0f;
    const float yaw = yaw_deg * (float)M_PI / 180.0f;
    setEulerRad(roll, pitch, yaw);
  }

  void setEulerRad(float roll, float pitch, float yaw) {
    const float cr = cosf(roll * 0.5f);
    const float sr = sinf(roll * 0.5f);
    const float cp = cosf(pitch * 0.5f);
    const float sp = sinf(pitch * 0.5f);
    const float cy = cosf(yaw * 0.5f);
    const float sy = sinf(yaw * 0.5f);

    q0_ = cr * cp * cy + sr * sp * sy;
    q1_ = sr * cp * cy - cr * sp * sy;
    q2_ = cr * sp * cy + sr * cp * sy;
    q3_ = cr * cp * sy - sr * sp * cy;
  }

 private:
  // Gyro-only integration (fallback when accel is invalid)
  // 纯陀螺仪积分（加速度计无效时的回退方案）
  void integrateGyroOnly(float gx_rads, float gy_rads, float gz_rads, float dt) {
    float q0 = q0_;
    float q1 = q1_;
    float q2 = q2_;
    float q3 = q3_;

    const float qDot0 = 0.5f * (-q1 * gx_rads - q2 * gy_rads - q3 * gz_rads);
    const float qDot1 = 0.5f * ( q0 * gx_rads + q2 * gz_rads - q3 * gy_rads);
    const float qDot2 = 0.5f * ( q0 * gy_rads - q1 * gz_rads + q3 * gx_rads);
    const float qDot3 = 0.5f * ( q0 * gz_rads + q1 * gy_rads - q2 * gx_rads);

    q0 += qDot0 * dt;
    q1 += qDot1 * dt;
    q2 += qDot2 * dt;
    q3 += qDot3 * dt;

    const float norm_q = sqrtf(q0 * q0 + q1 * q1 + q2 * q2 + q3 * q3);
    if (norm_q > 1e-6f) {
      q0 /= norm_q;
      q1 /= norm_q;
      q2 /= norm_q;
      q3 /= norm_q;
    }

    q0_ = q0;
    q1_ = q1;
    q2_ = q2;
    q3_ = q3;
  }

  float beta_ = 0.08f;
  float q0_ = 1.0f;
  float q1_ = 0.0f;
  float q2_ = 0.0f;
  float q3_ = 0.0f;
};



// ============================================================
// Mahony (Betaflight-style DCM) IMU Filter
// Mahony（Betaflight 风格 DCM）IMU 滤波器
// - Quaternion propagation with gyro / 四元数陀螺仪传播
// - Gravity correction from accelerometer / 加速度计重力校正
// - Optional integral feedback for gyro bias estimation
//   可选积分反馈用于陀螺仪偏置估计
// ============================================================
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

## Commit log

2025-12-17 大幅update
2025-12-17 設定画面を追加
2025-12-18 キャリブレーション機能追加
2025-12-18 ドリフトが改善せず。わからない。自作計算一回やめた方がいいかも
2025-12-18 符号間違え？
2025-12-18 可視化GUIを追加
2025-12-18 ジャイロの符号が反転してることが判明
2025-12-18 センサーの出力が逆なことが判明、修正したGUIも戻した。
2025-12-18 再アップ
2025-12-18 メッセージ表示とモーター数値バグ修正
2025-12-22 モーター番号修正、モーターテスト追加、飛び上がり死を防止
2025-12-22 Web UIの入力モード改善
2025-12-22 パラメータ調整
2025-12-28 いろいろ追加
    [drone_meishi.stl, drone_meishi3.step, drone_meishi_v2 v53.csv]
2026-04-18 ドキュメントをUpdate
    [drone_businesscard.csv, drone_meishi_v2 v53.csv]
2026-04-20 fix: bug fixes and bilingual comments (Chinese/English)
    Changes:
    - drone_pid.h: Add integral clamping to prevent windup
    - drone_imu.h: Add ACC calibration support with calibrateAccel()
    - drone_meishi.ino:
    * Remove unused LEDC channel constants
    * Increase telemetry buffer from 480 to 640 bytes
    * Add ACC calibration to WebSocket protocol (CAL,ACC)
    * Fix motor init order (check fault before writing)
    * Add bilingual comments (Chinese/English) throughout
    * Update CalRequest/CalState enums for ACC support
    [drone_imu.h, drone_meishi.ino]
2026-04-20 docs: add compilation guide and fix redundant code definition
    [drone_meishi.ino]
2026-04-21 docs: 增加陀螺仪算法优化方案 / add gyro algorithm optimization docs (2026-04-21)
